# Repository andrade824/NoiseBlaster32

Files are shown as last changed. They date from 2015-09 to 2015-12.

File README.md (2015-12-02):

## NoiseBlaster32
<p>The NoiseBlaster was developed as a joint project between <a href="https://www.linkedin.com/in/alex-lao-6b444766">Alex Lao</a> and myself during our free time after work while interning at Altera. Our goal was to design a music player from the ground up: from PCB design to firmware. In the span of only a month, we were able to accomplish this goal. The final product can play up to 512 audio files stored on an SD Card and has next/previous, play/pause, and volume up/down controls.</p>

### Hardware Design
<p>The PCB was designed using Altium Designer. We chose to use the PIC32MX270 because it contains an audio I2S (inter-inter sound) interface, was available in an easy-to-solder SOIC package, and we both had previous experience with the PIC32MX microcontroller series. To handle audio output, we chose the TI TLV320DAC23 for both digital to analog conversion and headphone amplification. This chip takes in audio data over I2S and outputs the amplified analog audio signals. It also contains an I2C interface for control purposes (changing volume and initialization). Special care was taken to minimize the noise on the audio lines in terms of the PCB design (carefully placed capacitors and ground fills).</p>
<p>To make this design as portable as possible, we also designed in a LiPo battery charging circuit (with a micro-USB port for charging and power purposes). A reset circuit is also included to make sure the components on the board don't get damaged or operate in a battery under-voltage situation.</p>
### Firmware Design
<p>The firmware consists of reading WAV files off of a FAT formatted SD card, decoding the audio data, and sending the data to the DAC over I2S. It also initializes all of the hardware components on the board (DAC, SD card, etc.) and uses interrupt-driven I/O for the control buttons (next/previous, play/pause, and volume up/down controls).A layered approach was taken to creating the firmware. Instead of creating one large chunk of code that read from the SD card and decoded data, we wrote separate drivers for SPI, SD Card I/O, reading files from FAT, and decoding WAV audio. Each of these layers works with the layer above and below it to get data from SD Card to DAC. This allowed us to split the work and debug our code far more easily than if we took a monolithic approach.</p>

<p>After stress testing how fast we could run the SPI signals to the SD Card, we found that we had more than enough bandwidth to play 16-bit WAV audio files recorded at a 44.1KHz sample rate. One of our biggest worries was that we wouldn't be able to read from the SD Card (and FAT filesystem in row) fast enough to play the audio data without skipping. When we created the drivers for the SD card and FAT filesystem, we designed everything around 512-byte chunks. This is because a single sector within the SD card is 512 bytes and it's far faster to read data on sector boundaries than not. We also utilized the DMA within the PIC32 to transfer data between the SPI and I2C modules without CPU intervention. That design coupled with designing our PCB so that we could run 20MHz SPI signals without any significant noise allowed us to play back audio at the standard sample rate of 44.1KHz.</p>

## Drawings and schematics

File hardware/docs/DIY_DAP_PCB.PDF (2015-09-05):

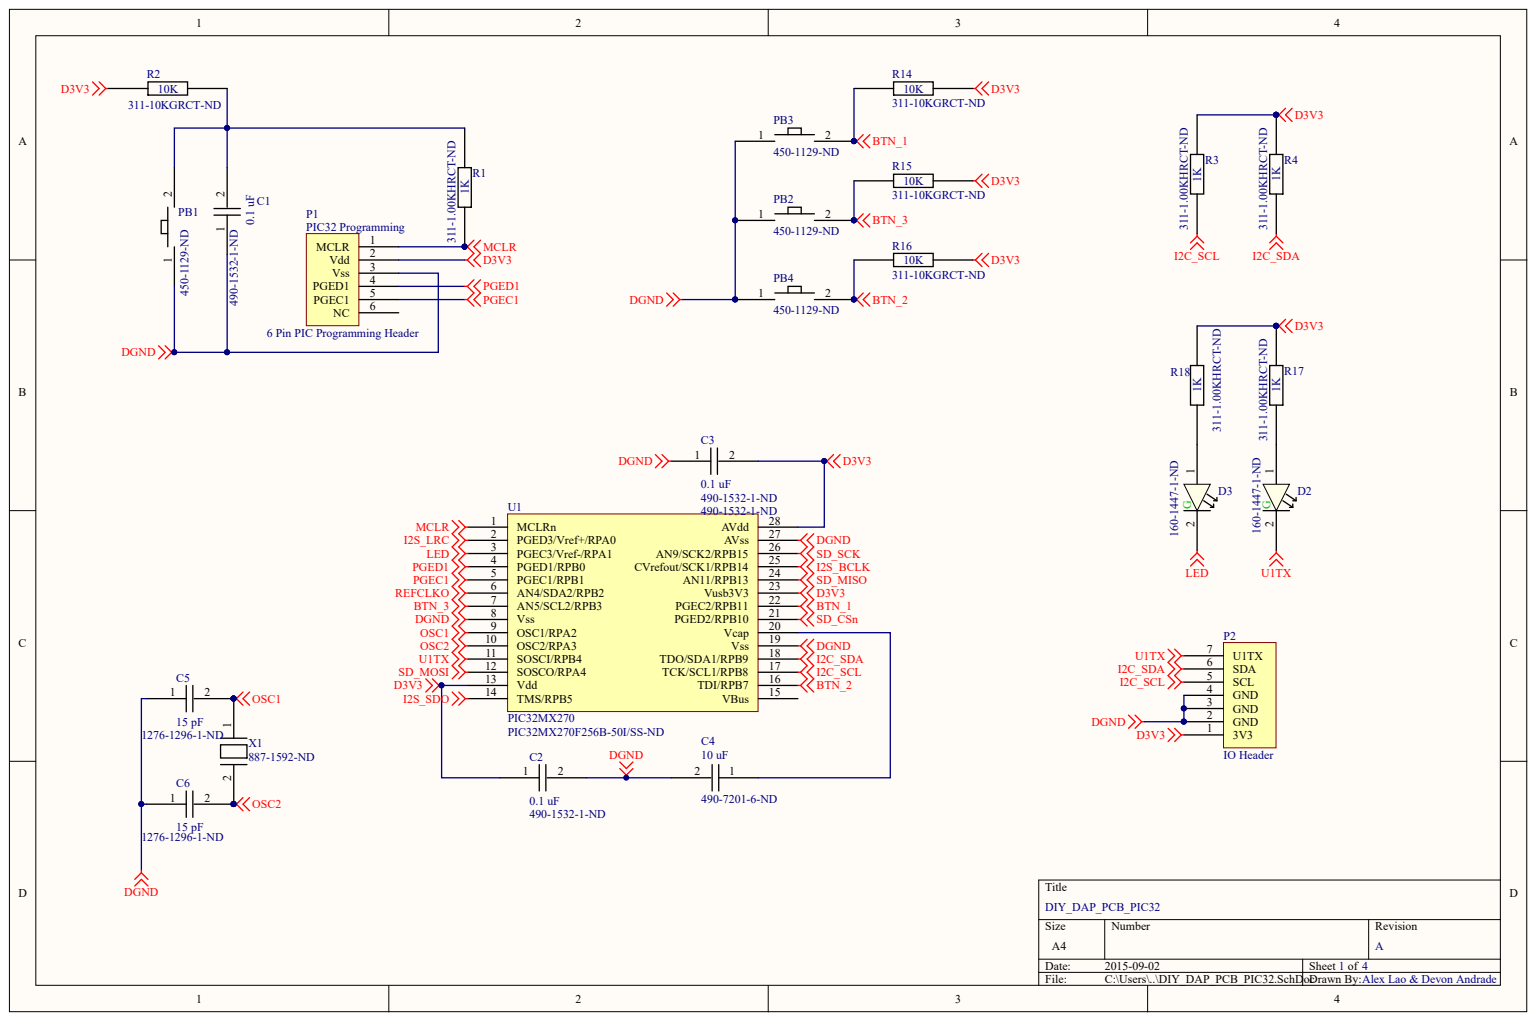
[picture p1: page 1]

6 Pin PIC Programming Header

Alex Lao & Devon Andrade A

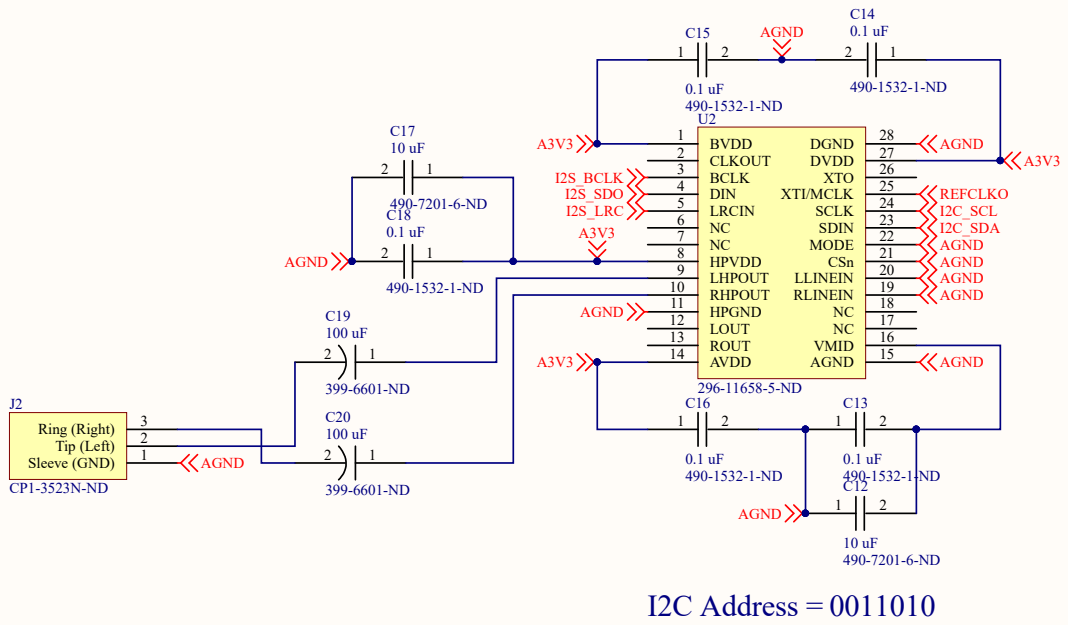
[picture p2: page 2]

Alex Lao & Devon Andrade

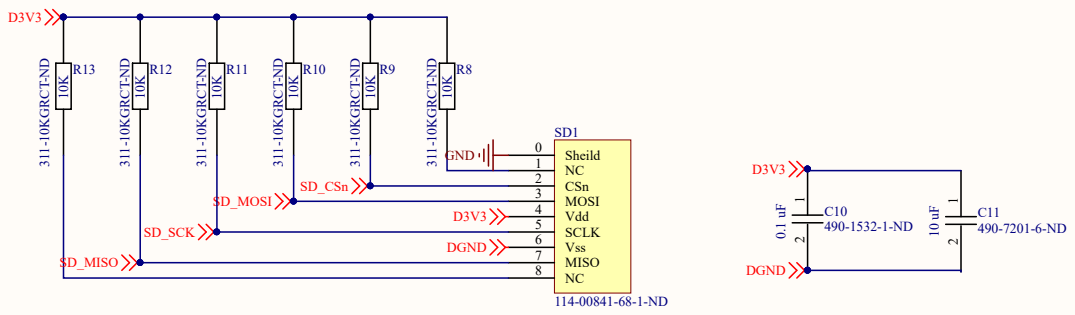
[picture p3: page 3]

Alex Lao & Devon Andrade A

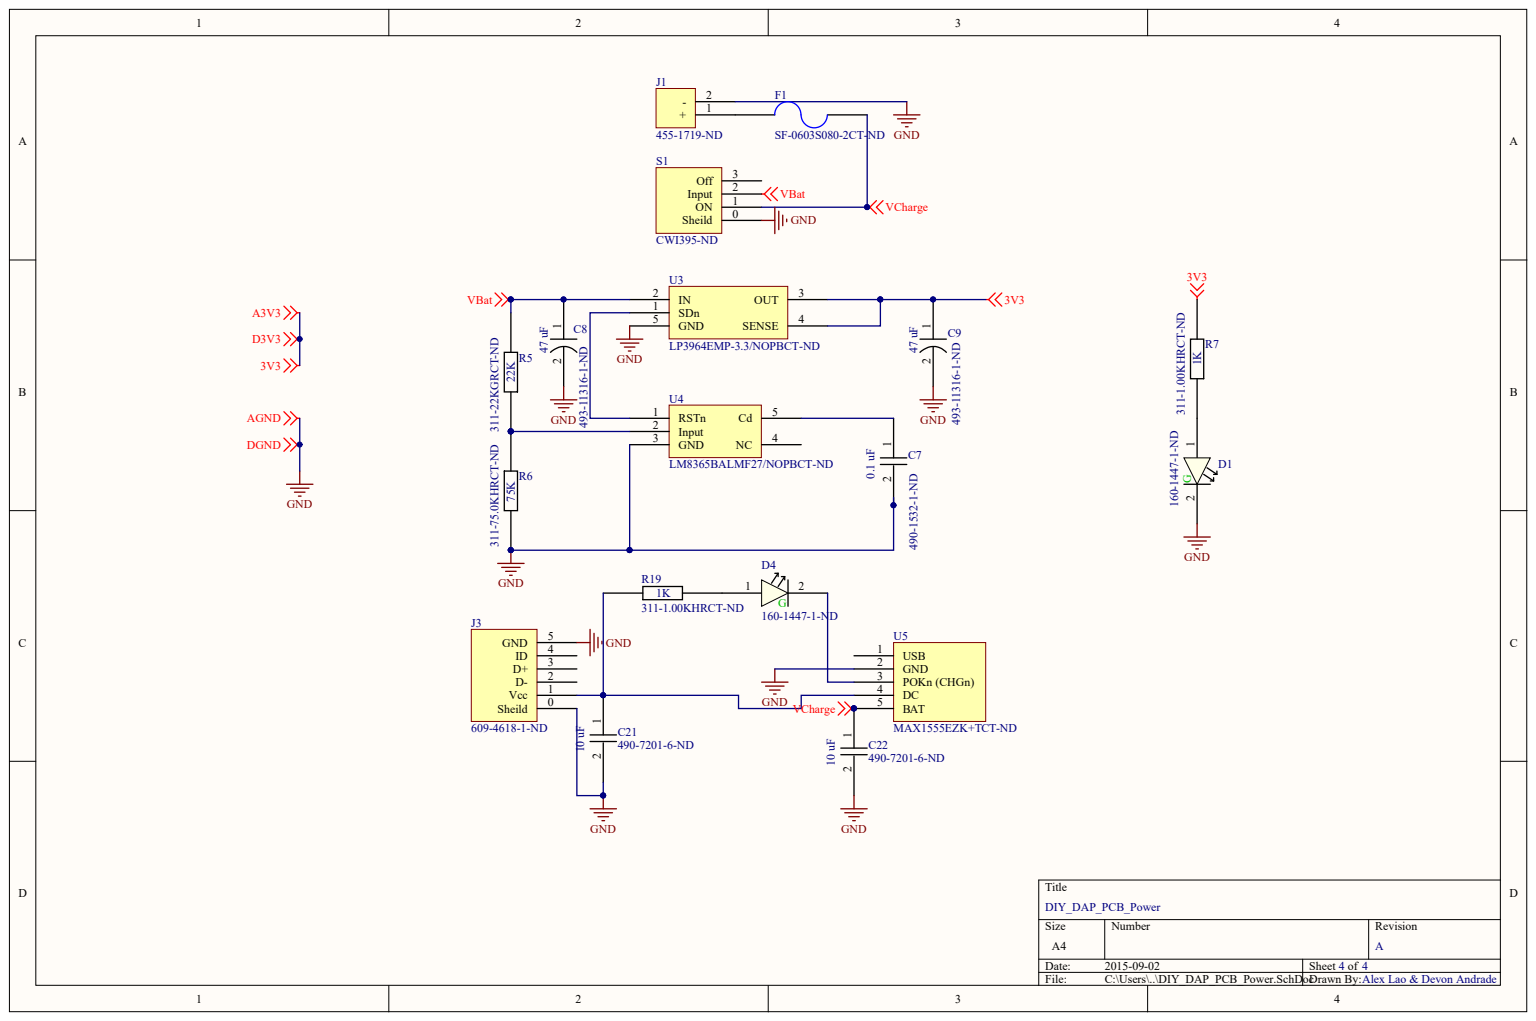
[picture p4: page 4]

Alex Lao & Devon Andrade A

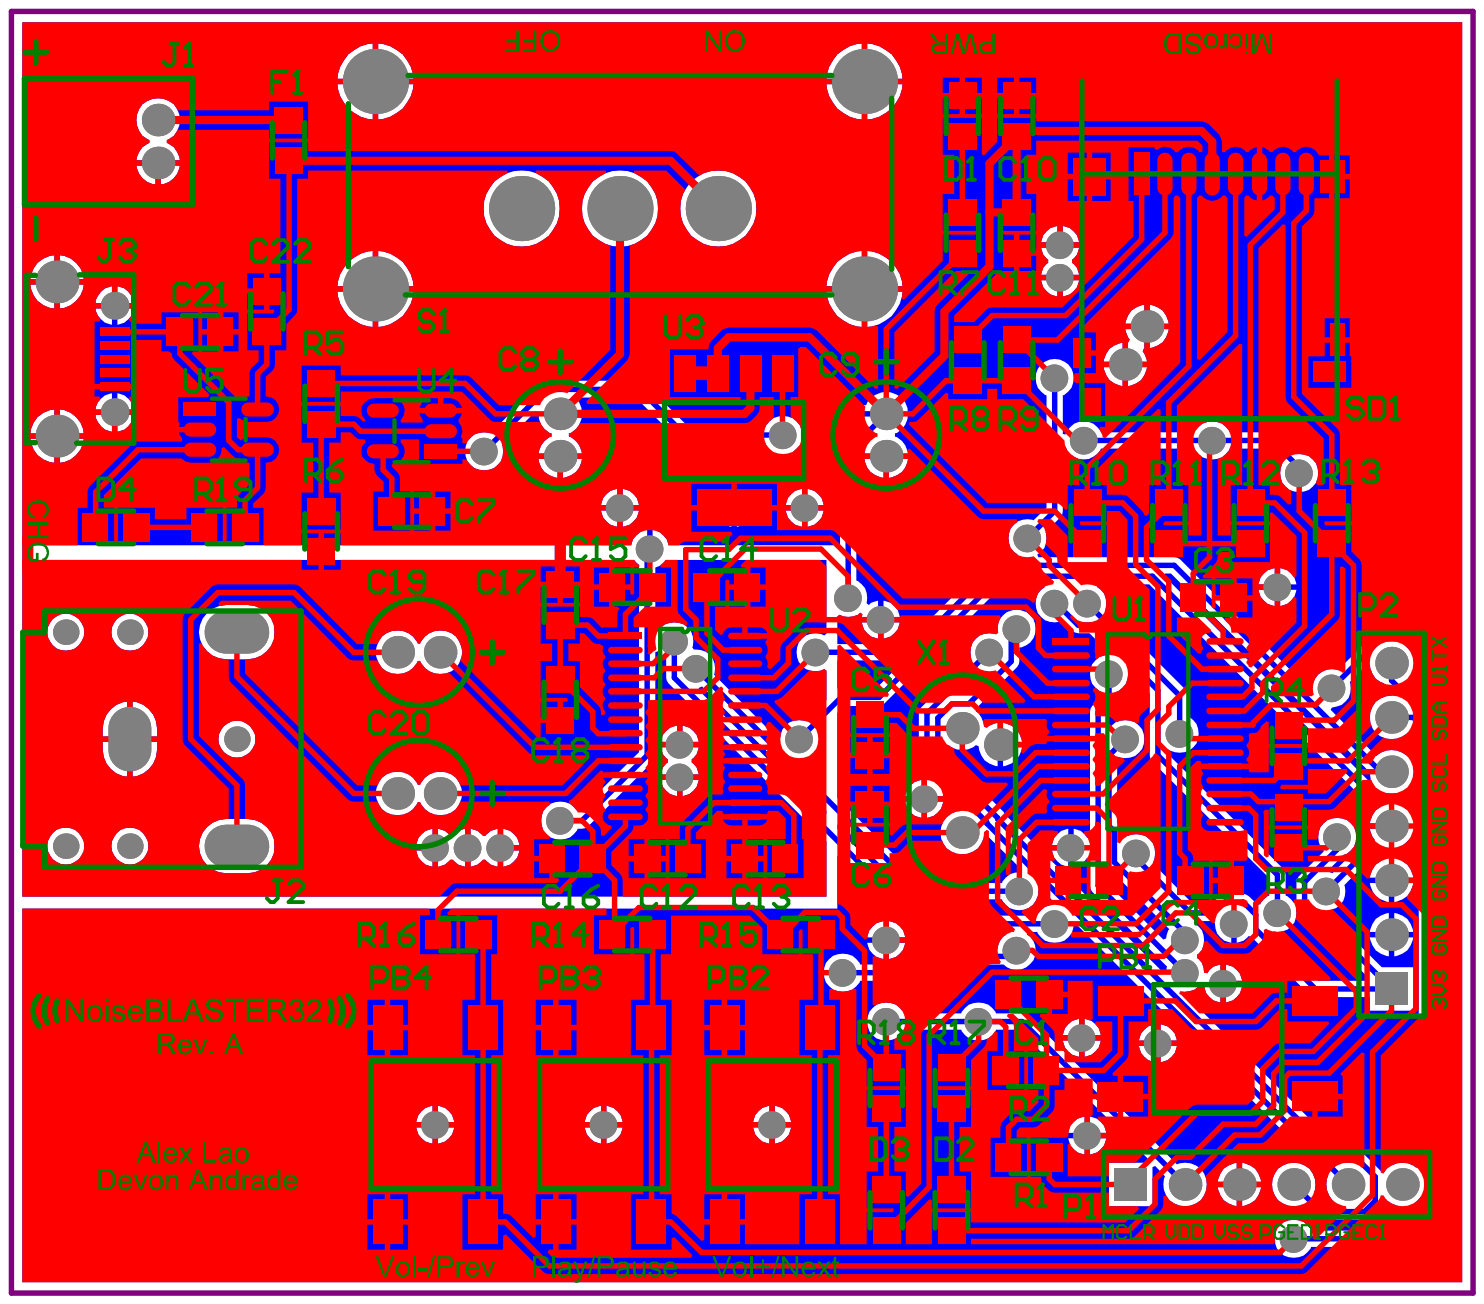
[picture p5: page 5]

Comment | Description | Designator | Footprint | LibRef | Quantity
490-1532-1-ND | 0603 0.1 uF - 16V -Ceramic Capacitor | C1, C2, C3, C7, C10, C13, C14, C15, C16, C18 | 0603 | 490-1532-1-ND | 10
490-7201-6-ND | 0603 10 uF - 16V -Ceramic Capacitor | C4, C11, C12, C17, C21, C22 | 0603 | 490-7201-6-ND | 6
1276-1296-1-ND | 0603 15 pF - 50V -Ceramic Capacitor | C5, C6 | 0603 | 1276-1296-1-ND | 2
493-11316-1-ND | 47 uF - 10V -Electrolytic Capacitor | C8, C9 | 493-11316-1-ND | 493-11316-1-ND | 2
399-6601-ND | 100 uF - 16V -Electrolytic Capacitor | C19, C20 | 399-6601-ND | 399-6601-ND | 2
160-1447-1-ND | Green LED (0603) | D1, D2, D3, D4 | 0603 | 160-1447-1-ND | 4
SF-0603S080-2CT-ND | 800 mA 32VDC Fuse | F1 | 0603 | SF-0603S080-2CT-ND | 1
455-1719-ND | JST-PH Battery Connector | J1 | 455-1719-ND | 455-1719-ND | 1
CP1-3523N-ND | 3.5mm Audio Jack | J2 | CP1-3523N-ND | CP1-3523N-ND | 1
609-4618-1-ND | USB Micro-B | J3 | 609-4618-1-ND | 609-4618-1-ND | 1
6 Pin PIC Programming Header | 6 Pin PIC Programming Header | P1 | PIC32 Programming Header | 6 Pin PIC Programming Header | 1
IO Header | | P2 | IO Header | IO Header | 1
450-1129-ND | Momentary Push button | PB1, PB2, PB3, PB4 | 450-1129-ND | 450-1129-ND | 4
311-1.00KHRCT-ND | 1k Ohm Resistor | R1, R3, R4, R7, R17, R18, R19 | 0603 | 311-1.00KHRCT-ND | 7
311-10KGRCT-ND | 10k Ohm Resistor | R2, R8, R9, R10, R11, R12, R13, R14, R15, R16 | 0603 | 311-10KGRCT-ND | 10
311-22KGRCT-ND | 22k Ohm Resistor | R5 | 0603 | 311-22KGRCT-ND | 1
311-75.0KHRCT-ND | 75k Ohm Resistor | R6 | 0603 | 311-75.0KHRCT-ND | 1
CWI395-ND | | S1 | CWI395-ND | CWI395-ND | 1
114-00841-68-1-ND | MicroSD Card Slot | SD1 | 114-00841-68-1-ND | 114-00841-68-1-ND | 1
PIC32MX270 | PIC32MX270F256B | U1 | PIC32MX270F256B-50I/SS-ND | PIC32MX270F256B-50I/SS-ND | 1
296-11658-5-ND | TLV320DAC23PW | U2 | 296-11658-5-ND | 296-11658-5-ND | 1
LP3964EMP-3.3/NOPBCT-ND | 3.3V LDO | U3 | LP3964EMP-3.3/NOPBCT-ND | LP3964EMP-3.3/NOPBCT-ND | 1
LM8365BALMF27/NOPB CT-ND | Undervoltage Reset Controller | U4 | LM8365BALMF27/NOPB CT-ND | LM8365BALMF27/NOPB CT-ND | 1
MAX1555EZK+TCT-ND | LiPo Charger | U5 | MAX1555EZK+TCT-ND | MAX1555EZK+TCT-ND | 1
887-1592-ND | 16.9344 Mhz Crystal | X1 | 887-1592-ND | 887-1592-ND | 1

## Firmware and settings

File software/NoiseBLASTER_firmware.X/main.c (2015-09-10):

/*  
 * File:   main.c
 * Author: Devon
 *
 * Created on August 17, 2015, 8:23 PM
 */
#define _SUPPRESS_PLIB_WARNING
 
#pragma config FPLLMUL = MUL_21, FPLLIDIV = DIV_4, FPLLODIV = DIV_2, FWDTEN = OFF
#pragma config POSCMOD = HS, FNOSC = PRIPLL, FPBDIV = DIV_1, ICESEL = ICS_PGx1

#pragma config FSOSCEN = OFF //SOSC OFF
#pragma config JTAGEN = OFF //JTAG OFF

#include <plib.h>
#include <stdlib.h>
#include <stdio.h>
#include <stdlib.h>
#include <stdint.h>
#include <stdbool.h>
#include "debug.h"
#include "sysclk.h"
#include "sd.h"
#include "uart.h"
#include "dma.h"
#include "i2c.h"
#include "dac.h"
#include "timer.h"
#include "wav.h"
#include "fat.h"

#define NUM_SECTORS 60

extern WAV_HEADER wavHeader;

enum buffer_type { FRONT, BACK };

// Flags to tell main to update data
volatile bool frontbuffer_done_sending = 0;
volatile bool backbuffer_done_sending = 0;
volatile enum buffer_type cur_buffer = FRONT;

volatile bool playing = true;

// Buffers to store audio data
int8_t frontbuffer[SECTOR_SIZE];
int8_t backbuffer[SECTOR_SIZE];

//Button Timer Flags
volatile bool vol_minus_pressed = false;
volatile bool play_pressed = false;
volatile bool vol_plus_pressed = false;
volatile bool vol_minus_held = false;
volatile bool play_held = false;
volatile bool vol_plus_held = false;

// Variables needed for FAT
#define MAX_FILES 100
struct FatPartition fat;
struct FatFile files[MAX_FILES];
uint16_t num_files = 0;
uint16_t current_song = 0;
uint32_t bytes_read = 0;

// Init functions
void InitPins(void);

//Music Controls
void play();
void pause();
void prevSong();
void nextSong();

int main(int argc, char** argv) 
{
    // Set flash wait states, turn on instruction cache, and enable prefetch
    SYSTEMConfig(SYS_FREQ, SYS_CFG_WAIT_STATES | SYS_CFG_PCACHE);
    
    // Wait to completely power up before
    int i = 0;
    for(i = 0; i < 1000000; i++);
    
    // Enable multi vectored interrupts
    INTEnableSystemMultiVectoredInt(); //Do not call after setting up interrupts
    
    // Initialize each of the subsystems
    InitPins();
    InitUART1();
    InitDAC();
    InitSD();
    InitTimer25Hz();
    InitDMA();
    
    // Start up FAT stuff and open a file
    OpenFirstFatPartition(&fat);
    num_files = GetFilesByExt(&fat, files, MAX_FILES, "WAV");
    
    if(num_files == 0)
    {
        DEBUG_LED_ON();
        while(1) { }
    }
    
    Fat_read(&(files[current_song]), (void*)frontbuffer, SECTOR_SIZE);
    readWavHeader(frontbuffer);
    
    Fat_read(&(files[current_song]), (void*)frontbuffer, SECTOR_SIZE);
    Fat_read(&(files[current_song]), (void*)backbuffer, SECTOR_SIZE);
    
    // Enable global interrupts
    asm volatile("ei");
    
    //TestWavHeader();
    
    // Set the SIRQEN and CFORCE bits to start a DMA transfer
    DCH0ECONSET = 0x90;
    
    while(1){
        // Disable interrupts to avoid read/write problems when reading variables accessed by interrupts
        // Disable interrupts to avoid crashes during I2C read when an interrupt fires during transmission
        // Enable interrupts at the end of the loop
        asm volatile("di");
        if(playing){
            if (frontbuffer_done_sending){
                frontbuffer_done_sending = false;

                bytes_read = Fat_read(&(files[current_song]), (void*)frontbuffer, SECTOR_SIZE);

                if(bytes_read < SECTOR_SIZE)
                {
                    nextSong();
                }
            }

            if (backbuffer_done_sending){
                backbuffer_done_sending = false;

                bytes_read = Fat_read(&(files[current_song]), (void*)backbuffer, SECTOR_SIZE);

                if(bytes_read < SECTOR_SIZE)
                {
                    nextSong();
                }
            }
        }
        
        if (vol_plus_pressed == true){
            DAC_VolumeUP();
            vol_plus_pressed = false;
        }
        if (vol_plus_held == true){
            nextSong();
            vol_plus_held = false;
        }
        
        if (play_pressed == true){
            play_pressed = false;
            if(playing){
                pause();
            }else{
                play();
            }
        }
        else if (play_held == true){
            play_held = false;
            if(playing){
                pause();
            }else{
                play();
            }
        }
        
        if (vol_minus_pressed == true){
            DAC_VolumeDOWN();
            vol_minus_pressed = false;
        }
        if (vol_minus_held == true){
            prevSong(); 
            vol_minus_held = false;
        }
        asm volatile("ei");
    }
    
    return (EXIT_SUCCESS);
}

void play(){
    playing = true;
    DAC_DigitalControl(false);
    DmaChnIntEnable(0);
}

void pause(){
    playing = false;
    DAC_DigitalControl(true);
    DmaChnIntEnable(0);
}

void nextSong(){
    DAC_DigitalControl(true);
    if(current_song == num_files-1){
        current_song = 0;
    }else{
        current_song = (current_song + 1) % num_files;
    }
    
    ResetFile(&(files[current_song]));
    Fat_read(&(files[current_song]), (void*)frontbuffer, SECTOR_SIZE);
    readWavHeader(frontbuffer);

    Fat_read(&(files[current_song]), (void*)frontbuffer, SECTOR_SIZE);
    Fat_read(&(files[current_song]), (void*)backbuffer, SECTOR_SIZE);
    backbuffer_done_sending = false;
    frontbuffer_done_sending = false;
    DAC_DigitalControl(false);
}

void prevSong(){
    DAC_DigitalControl(true);
    if(current_song == 0){
        current_song = num_files-1;
    }else{
        current_song = (current_song - 1) % num_files;
    }
    
    ResetFile(&(files[current_song]));
    Fat_read(&(files[current_song]), (void*)frontbuffer, SECTOR_SIZE);
    readWavHeader(frontbuffer);

    Fat_read(&(files[current_song]), (void*)frontbuffer, SECTOR_SIZE);
    Fat_read(&(files[current_song]), (void*)backbuffer, SECTOR_SIZE);
    backbuffer_done_sending = false;
    frontbuffer_done_sending = false;
    DAC_DigitalControl(false);
}

void InitPins(void)
{
    // Set all pins to be digital (no analog 4 u)
    ANSELA = 0;
    ANSELB = 0;
    
    // Debug LED Pin
    mPORTAClearBits(BIT_1);
    mPORTASetPinsDigitalOut(BIT_1);
    mPORTASetBits(BIT_1);
   
    //Volume Minus Button Pin
    mPORTBClearBits(BIT_7);
    mPORTBSetPinsDigitalIn(BIT_7);
    //Play Button Pin
    mPORTBClearBits(BIT_11);
    mPORTBSetPinsDigitalIn(BIT_11);
    //Volume Plus Button Pin
    mPORTBClearBits(BIT_3);
    mPORTBSetPinsDigitalIn(BIT_3);
    
    // SS on SPI1 (SD Card) Pin
    mPORTBClearBits(BIT_10);
    mPORTBSetPinsDigitalOut(BIT_10);
    mPORTBSetBits(BIT_10);
    
    /* All of the Peripheral Pin Select (PPS) Configuration */
    
    // I2S (SPI1) PPS
    mPORTASetPinsDigitalOut(BIT_0);     // Slave Select 1 (SS1)
    mPORTBSetPinsDigitalOut(BIT_5);     // Serial Digital Out (SDO1)
    mPORTBSetPinsDigitalOut(BIT_2);     // I2S Master Clock (REFCLKO)
    mPORTBSetPinsDigitalOut(BIT_14);    // Shift Clock 1 (SCK1)
    
    // SD Card (SPI2) PPS
    mPORTBSetPinsDigitalIn(BIT_13);     // Serial Data In 2 (SDI2)
    mPORTBSetPinsDigitalOut(BIT_10);    // Slave Select 2 (SS2)
    mPORTASetPinsDigitalOut(BIT_4);      // Serial Data Out 2 (SDO2)
    mPORTBSetPinsDigitalOut(BIT_15);    // Shift Clock 2 (SCK2)
    
    // UART PPS
    mPORTBSetBits(BIT_4); //UART1 TX Pin
    mPORTBSetPinsDigitalOut(BIT_4);     // UART 1 Transmit (U1TX)
 
    //Pin mapping Config - See Table 11-1 and 11-2 in the PIC32MX1XX/2XX Data Sheet
    PPSUnLock; // Allow PIN Mapping
    PPSOutput(1, RPA0, SS1);
    PPSOutput(2, RPB5, SDO1);
    PPSOutput(3, RPB2, REFCLKO);
    
    PPSInput(3, SDI2, RPB13);
    PPSOutput(4, RPB10, SS2);
    PPSOutput(3, RPA4, SDO2);
    
    PPSOutput(1, RPB4, U1TX);
    PPSLock; // Prevent Accidental Mapping
}

static enum {
    EXCEP_IRQ = 0,            // interrupt
    EXCEP_AdEL = 4,            // address error exception (load or ifetch)
    EXCEP_AdES,                // address error exception (store)
    EXCEP_IBE,                // bus error (ifetch)
    EXCEP_DBE,                // bus error (load/store)
    EXCEP_Sys,                // syscall
    EXCEP_Bp,                // breakpoint
    EXCEP_RI,                // reserved instruction
    EXCEP_CpU,                // coprocessor unusable
    EXCEP_Overflow,            // arithmetic overflow
    EXCEP_Trap,                // trap (possible divide by zero)
    EXCEP_IS1 = 16,            // implementation specfic 1
    EXCEP_CEU,                // CorExtend Unuseable
    EXCEP_C2E                // coprocessor 2
} _excep_code;
static unsigned int _epc_code;
static unsigned int _excep_addr;

// this function overrides the normal _weak_ generic handler
void _general_exception_handler(void)
{
    asm volatile("mfc0 %0,$13" : "=r" (_excep_code));
    asm volatile("mfc0 %0,$14" : "=r" (_excep_addr));
    _excep_code = (_excep_code & 0x0000007C) >> 2;    
    while (1) {
        DEBUG_LED_ON();
    }
}

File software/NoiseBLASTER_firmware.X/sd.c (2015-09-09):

#include "sd.h"

/**
 * Initialize SPI2 (used to interface with the SD Card)
 */
static void InitSPI2(void)
{
    SET_SS();   // De-select the SD card

    // Init the spi module for a slow (init) clock speed, 8 bit byte mode
    SPI2CONbits.ON = 0; // Disable SPI for configuration
    
    SPI2BUF;    // Clear the receive buffer
    SPI2STATbits.SPIROV = 0;    // Clear the receive overflow bit
    SPI2CON = 0x260;    // Master, CKE=0; CKP=1, sample end (dude on internet says this works)
    SPI2BRG = 128;  // Divide by 512. SCK = Fpb/(2 * (BRG + 1)), aka, 156.25KHz
    
    SPI2CONbits.ON = 1; // enable
}

/**
 * Initialize the SPI connected to the SD Card, and the SD Card itself
 */
void InitSD(void)
{
    int i = 0;
    uint8_t response = 0;
    
    // Initialize the SPI
    InitSPI2();
    
    SD_Disable();   // 1. start with the card not selected
    for ( i = 0; i < 10; i++)   // 2. send 80 clock cycles so card can init registers
        SD_Clock();
    SD_Enable();    // 3. now select the card
    
    // 4. send a reset command and look for "IDLE"
    response = SD_SendCmd(0, 0, 0x95); 
    if (response != 1) {
        SD_Disable();
        UART_SendString("Response: ");
        UART_SendInt(response);
        UART_SendString("\n\rError: Card isn't in IDLE state out of reset. Did you plug it in and apply power?\n\r");
        return;
    }
    
    SD_Enable();
    // 5. Attempt to identify the card
    response = 0xFF;    // Make sure the response isn't zero before starting loop
    while(response != 0xAA)//Verify that the SD card is an SDHC card
    {
        // need to constantly send this command and wait until response is zero
        response = SD_SendCmd(8, 0x1AA, 0x87);
        
        //Read 32bit response, keep last one
        response = SD_Read();
        response = SD_Read();
        response = SD_Read();
        response = SD_Read();
    }
    
    // 6. Attempt to initialize the card
    //ACMD41
    response = 0xFF;
    while(response != 0x00)
    {
        response = SD_SendCmd(55, 0, 0);
        response = SD_SendCmd(41, 1<<30, 0);
    }
    
    //We need to add this back and check the response from CMD58 to check if the SD card is byte or block addressed
    // 6. Set the block size to 512 bytes
    //SD_SendCmd(16, SECTOR_SIZE, 0);
    
    // 7. Reconfigure the SPI to use a faster clock now that we know the SD card works
    SET_SS();   // De-select the SD card

    SPI2CONbits.ON = 0; // Disable SPI for configuration
    SPI2BRG = 0;  // SCK = Fpb/(2 * (BRG + 1))
    SPI2CONbits.ON = 1; // enable
    
    UART_SendString("Card is initialized\n\r");
}

/**
 * Send out a single byte and receive a byte
 * 
 * @param data The byte of data to send
 * 
 * @return The byte of data that was received
 */
uint8_t SPI_Write(uint8_t data)
{
    SPI2BUF = data;                    // write to buffer for TX
    while(!SPI2STATbits.SPIRBF);    // wait for transfer to complete
    SPI2STATbits.SPIROV = 0;        // clear any overflow.

    return SPI2BUF;                    // read the received value
}

/**
 *  Send an SPI mode command to the SD card.
 *
 *  @param cmd  The SD card command to send
 *  @param addr The 32-bit argument to pass along with the command.
 *                  Typically an address for a read/write.
 *  @param crc  The CRC value for this command, only used for the init command.
 * 
 *  @return status read back from SD card (0xFF is a fault)
 *
 *    Expected return responses:
 *      FF - timeout 
 *      00 - command accepted
 *      01 - command received, card in idle state after RESET
 *
 *    R1 response codes (how to decode the response for most commands):
 *      bit 0 = Idle state
 *      bit 1 = Erase Reset
 *      bit 2 = Illegal command
 *      bit 3 = Communication CRC error
 *      bit 4 = Erase sequence error
 *      bit 5 = Address error
 *      bit 6 = Parameter error
 *      bit 7 = Always 0
 */
uint8_t SD_SendCmd(uint8_t cmd, uint32_t addr, uint8_t crc)
 {
    uint16_t n;
    uint8_t res;

    //Alex - Commented out because it breaks multicycle responses (R7 response from CM8))
    //SD_Enable(); // enable SD card

    SPI_Write(cmd | 0x40); // send command packet (6 bytes)
    SPI_Write((addr>>24) & 0xFF); // msb of the address/argument
    SPI_Write((addr>>16) & 0xFF);
    SPI_Write((addr>>8) & 0xFF);
    SPI_Write((addr) & 0xFF); // lsb
    SPI_Write(crc); // Not used unless CRC mode is turned back on for SPI access.

    // TODO: Change this to a for loop, should be easier to read
    n = 9; // now wait for a response (allow for up to 8 bytes delay)
    do {
        res = SD_Read(); // check if ready   
        if ( res != 0xFF) 
            break;
    } while ( --n > 0);

    //Alex - Commented out because it breaks multicycle responses (R7 response from CM8))
    //SD_Disable();
    
    return (res); // return the result that we got from the SD card.
 }

/**
 * Read a variable amount of bytes off of the SD card starting at a specific
 * byte address.
 * 
 * @param buffer        The buffer to put data into
 * @param start_byte    The byte address to start reading from
 * @param size          How many bytes to read
 * 
 * NOTE: With this implementation, only SECTOR_SIZE number of bytes can be
 * safely read. Modifications need to be made to read more than SECTOR_SIZE
 * number of bytes safely and efficiently.
 */
void SD_ReadData(void * buffer, uint32_t start_byte, size_t size)
{
    // Buffers to hold data across sector boundaries
    uint8_t intermediate[MAX_SD_BUFFERS][SECTOR_SIZE];
    int i = 0, j = 0;
    
    // How many bytes it takes up adding the bytes from the start of the sector
    int size_from_start = size + (start_byte % SECTOR_SIZE);
    
    // Check if size is outside the boundaries and force to upper limit if so
    if(size > ((MAX_SD_BUFFERS - 1) * SECTOR_SIZE))
        size = (MAX_SD_BUFFERS - 1) * SECTOR_SIZE;
    
    // Operation fits within a single sector read
    if(size_from_start <= SECTOR_SIZE)
        SD_ReadSector((uint8_t *)intermediate, SECTOR_NUM(start_byte));
    else
        // Operation will cross sector boundaries, do a multi-sector read
        SD_ReadMultiSectors(intermediate, SECTOR_NUM(start_byte), MAX_SD_BUFFERS);
    
    // Move from the intermediate buffer into the requested buffer
    for(i = start_byte % SECTOR_SIZE; j < size; ++i, ++j)
        *((uint8_t *)buffer + j) = intermediate[SECTOR_NUM(i)][i % SECTOR_SIZE];
}
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

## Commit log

2015-09-03 Initial commit of the firmware.
    Low level SD Card driver functions finished, and the DMA functions are for the most part finished.
2015-09-05 Added I2C and DAC I2C configuration functions
2015-09-05 Added Altium Library and PCB files, Updated gitignore for Altium
    [DIY_DAP_PCB.PcbDoc, DIY_DAP_PCB.PrjPCB, DIY_DAP_PCB_Audio.SchDoc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]
2015-09-05 Add pin initialization function
    This single function sets up all of the functions for every peripheral (PPS and regular GPIO)
2015-09-05 Clean DAC and I2C subsystems (style fixes, warning fixes, etc.)
    [dac.c, i2c.c, i2c.h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]
2015-09-05 Increased I2C Speed, Changed SD support to SDHC
    I2C now runs at 400 kHz
    SD library now supports only SDHC cards
2015-09-06 Added Timer, Currently the wrong frequency
    [main.c]
2015-09-06 Modify DAC initialization code to actually work. DMA is sending a sine wave!
2015-09-07 Fixed timers, added button handling, added WAV header reading
    Timer intterupt now fires at 25 Hz
    Buttons now control volume when pressed or frequency when held
    WAV file header read from SD card sector 0 and output over UART
    [dac.c, dma.c, main.c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]
2015-09-07 RAW SD WAV audio playback working
    BUG: PIC32 reboots after about 3-4 minutes of playback for some reason
    Hold Prev/Next button to seek forward or backward about a minute
    [dac.c, dma.c, main.c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]
2015-09-08 Fixed DMA, I2C and timer interrupt related crashes
    Moved DAC volume control to the main loop and used flags to allow the button interrupt to trigger it
    Disable interrupts going into the main loop and enable interrupts exiting the main loop to avoid problems
    [dma.c, main.c]
2015-09-10 Added Play/Pause, Created Prev/Next functions, Reduce Pops
    Reduced pops when changing tracks by skipping past non-audio data and muting the DAC during track change
    [main.c]
